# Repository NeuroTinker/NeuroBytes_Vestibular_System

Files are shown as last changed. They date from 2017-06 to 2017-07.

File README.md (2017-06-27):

# NeuroBytes Vestibular System
NeuroBytes are open-source hardware neuron simulators designed and sold by [NeuroTinker, LLC](http://www.neurotinker.com/). The Vestibular System boards emulate the portion of the inner ear responsible for orientation.  

All NeuroBytes products are based on the ST32L0x series of ARM Cortex-M0+ 32-bit microcontrollers. The boards were designed in KiCad and Inkscape and are released under the terms of the GPL, v3.0.

This repository is a continuation of the 8-bit ATtiny design called [NeuroBytes v0.91](https://github.com/zakqwy/neurobytes). The two series are not compatible.

## Project Status
This project is in alpha. The firmware is in progress and the API may change at any time. The PCB design is physically tested but has not yet been manufactured at scale.

## More Information
The NeuroBytes GitHub repositories store engineering information and make the design history of the project available to the public. Hardware- and firmware-specific README.md files can be found in their appropriate subdirectories. 

We encourage community involvement in our efforts, keeping in mind that hardware availability is currently quite limited. For product availability, operating guidelines, curricula, and information about NeuroTinker, LLC, head to neurotinker.com. Further technical logs are also at https://hackaday.io/project/3339-neurobytes.

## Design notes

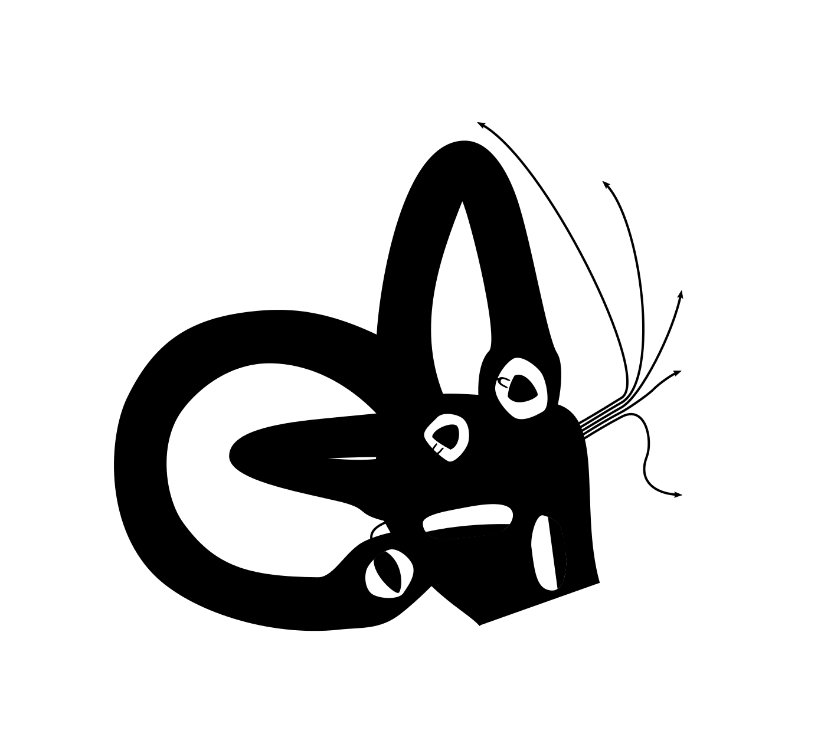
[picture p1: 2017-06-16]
HARDWARE/cu.png

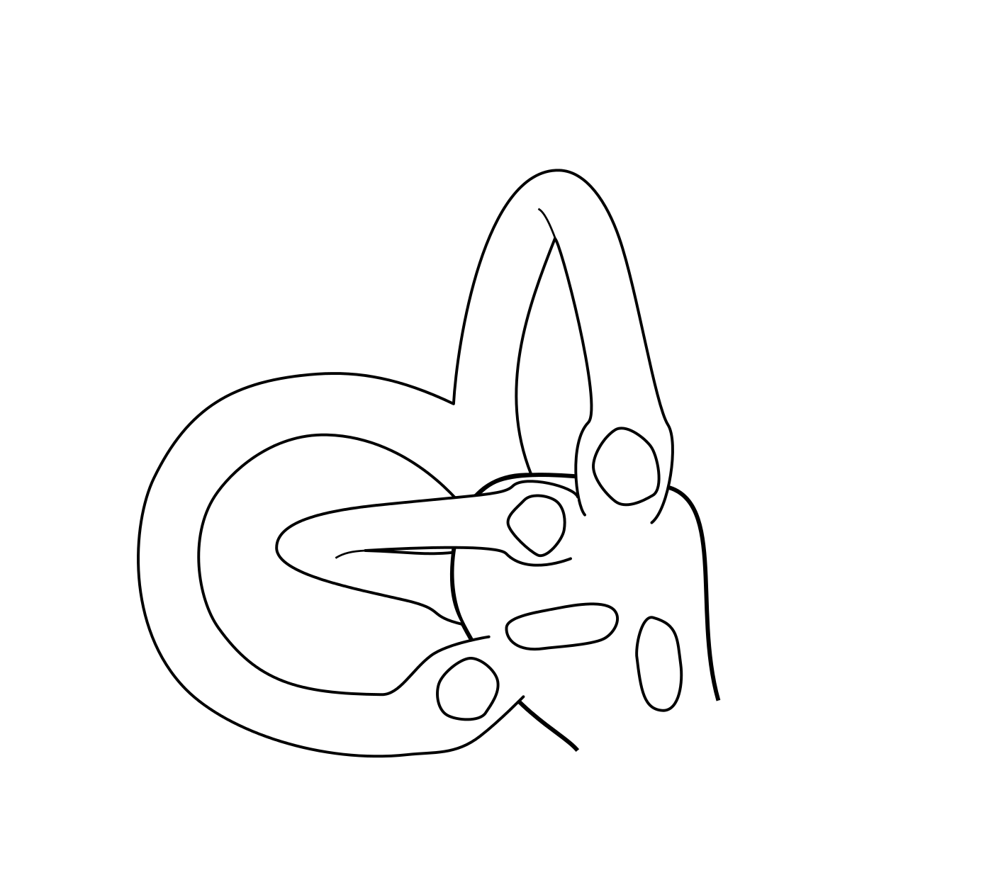
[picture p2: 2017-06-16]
HARDWARE/silk.png

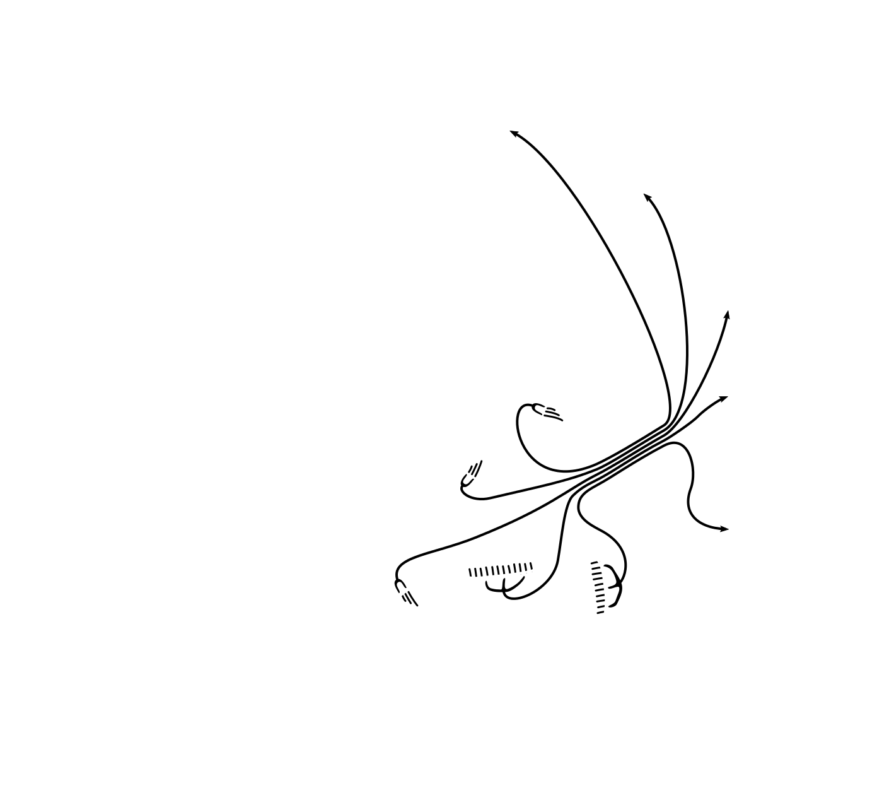
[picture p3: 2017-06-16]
HARDWARE/mask.png

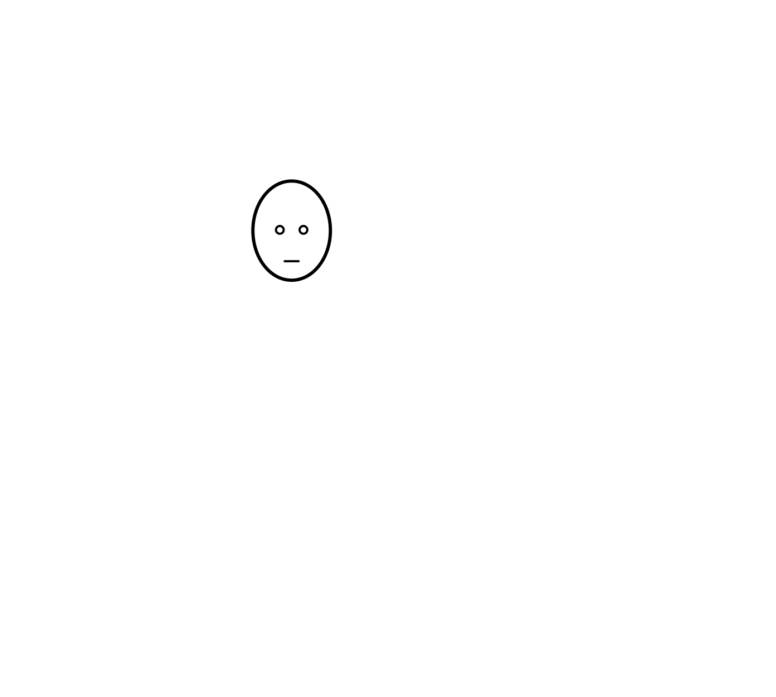
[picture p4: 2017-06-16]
HARDWARE/face.png

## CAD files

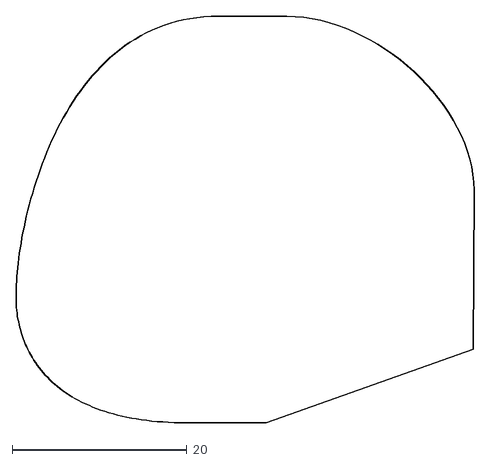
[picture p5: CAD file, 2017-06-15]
HARDWARE/NeuroBytes_Vestibular_System.dxf
52.3 x 46.4

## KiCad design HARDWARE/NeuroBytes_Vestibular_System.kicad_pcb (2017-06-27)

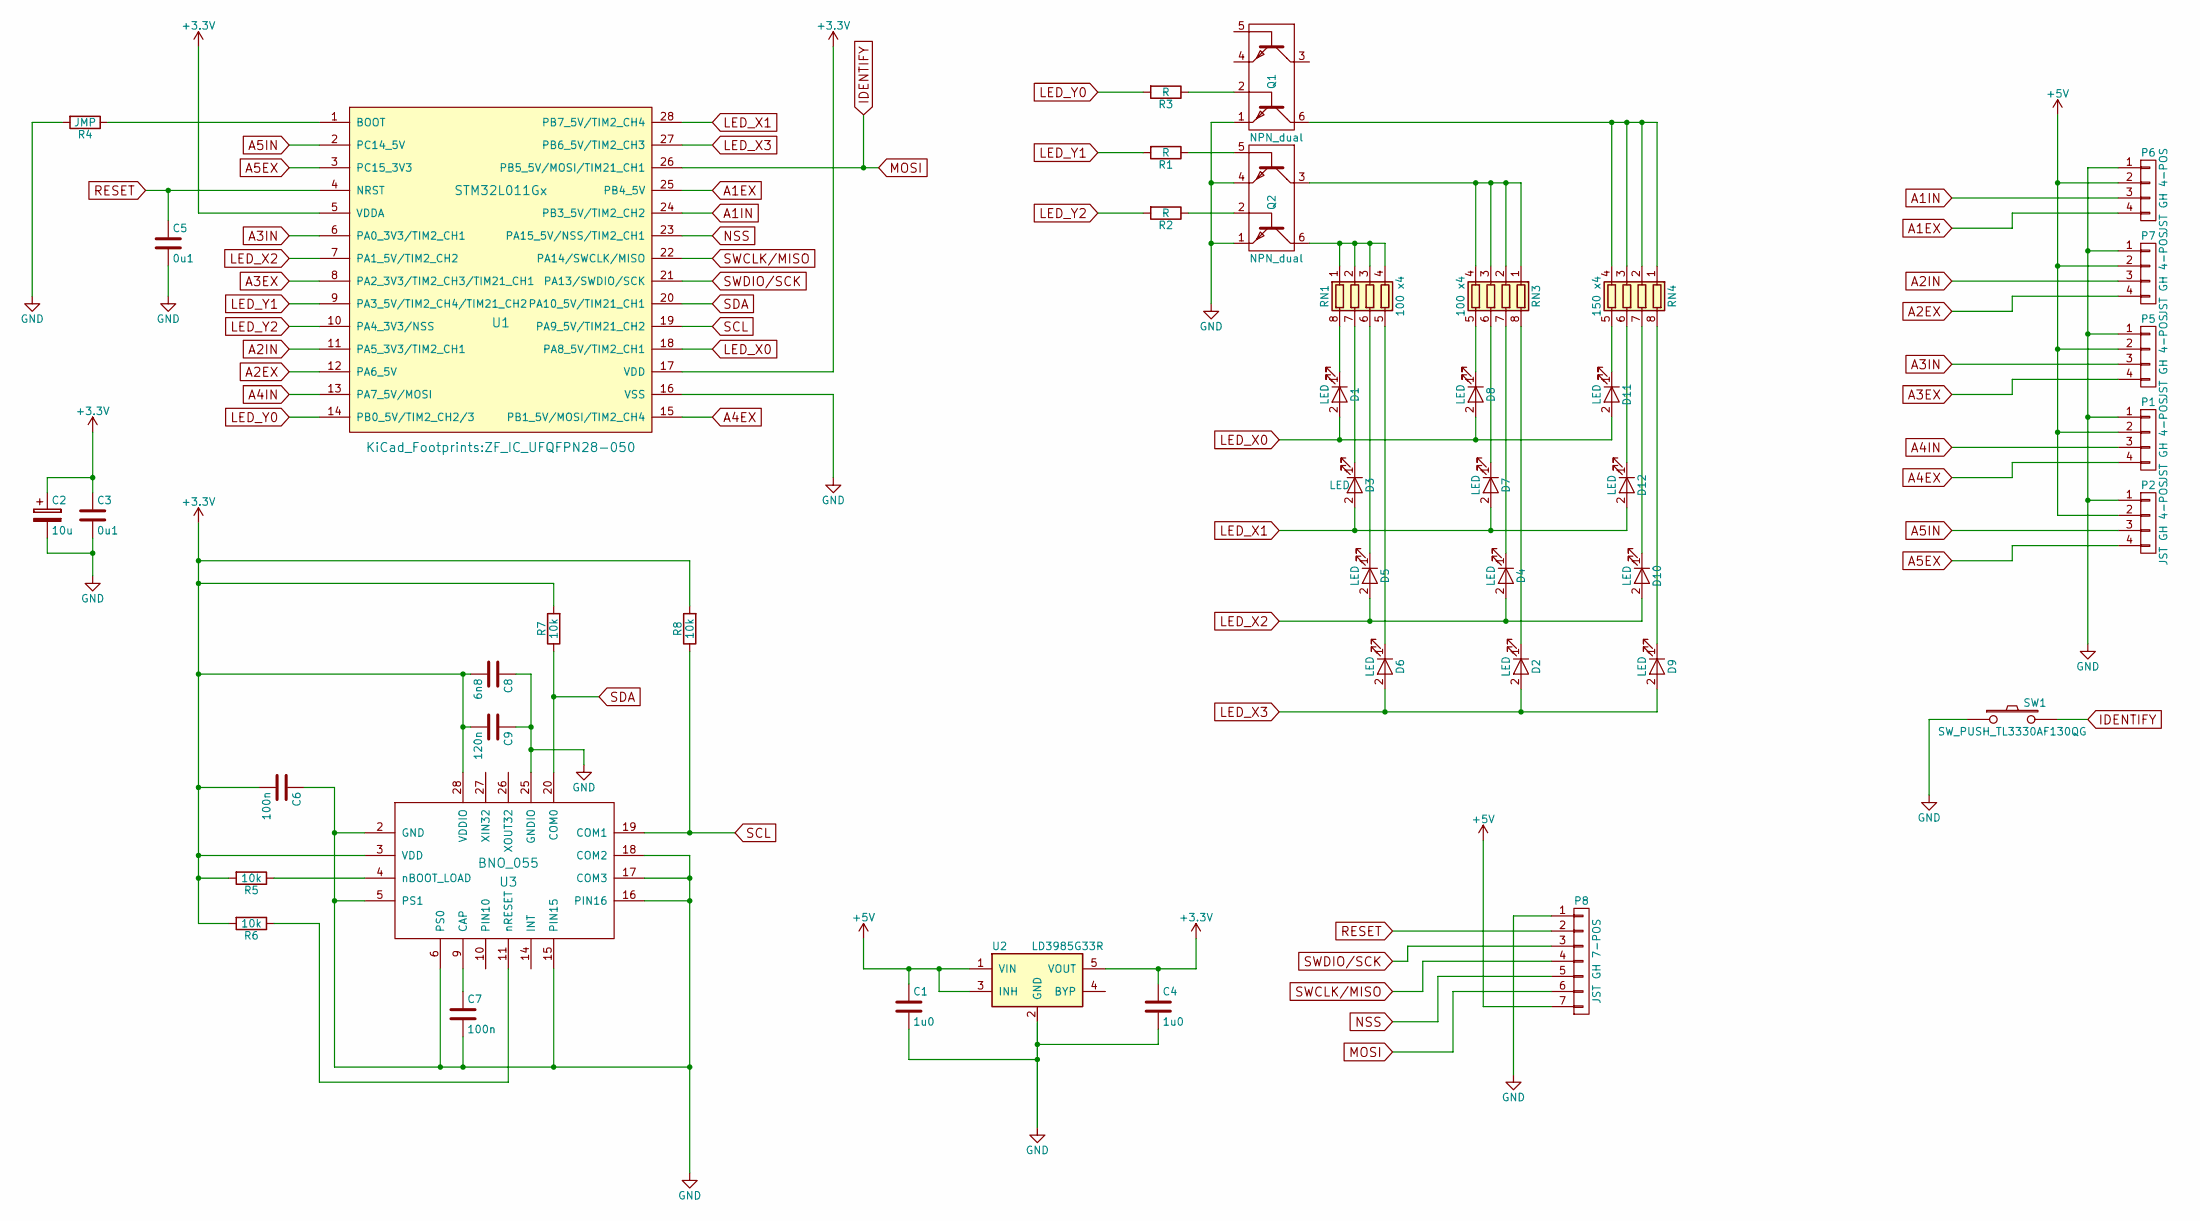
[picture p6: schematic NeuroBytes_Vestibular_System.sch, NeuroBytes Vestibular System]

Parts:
C1, C4: 1u0; ZF_SMD_NonPol_0603
C2: 10u; ZF_SMD_pol_1206
C3, C5: 0u1; ZF_SMD_NonPol_0402_cap
C6, C7: 100n; ZF_SMD_NonPol_0402_cap
C8: 6n8; ZF_SMD_NonPol_0402_cap
C9: 120n; ZF_SMD_NonPol_0402_cap
D1, D2, D3, D4, D5, D6, D7, D8, D9, D10, D11, D12: LED; ZF_SMD_NonPol_0402
P1, P2, P5, P6, P7: JST GH 4-POS; ZF_CONN_JST_GH
P8: JST GH 7-POS; ZF_CONN_JST_GH_7POS
Q1, Q2: NPN_dual; ZF_SMD_SOT-363
R1, R2, R3: R; ZF_SMD_NonPol_0402
R4: JMP; ZF_SMD_NonPol_0402
R5, R6, R7, R8: 10k; ZF_SMD_NonPol_0402
RN1, RN3: 100 x4; ZF_RN_4iso_CTS-0804
RN4: 150 x4; ZF_RN_4iso_CTS-0804
SW1: SW_PUSH_TL3330AF130QG; ZF_SW_Momentary_SideMtg
U1: STM32L011Gx; ZF_IC_UFQFPN28-050
U2: LD3985G33R; ZF_SOT23-5L
U3: BNO_055; ZF_IC_28LGA

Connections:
+3V3: C2.1, C3.1, C4.1, C6.2, C8.2, C9.2, R5.2, R6.2, R7.2, R8.2, U1.5 (VDDA), U1.17 (VDD), U2.5 (VOUT), U3.3 (VDD), U3.28 (VDDIO)
+5V: C1.1, P1.2, P2.2, P5.2, P6.2, P7.2, P8.7, U2.1 (VIN), U2.3 (INH)
A1EX: P6.4, U1.25 (PB4_5V)
A1IN: P6.3, U1.24 (PB3_5V/TIM2_CH2)
A2EX: P7.4, U1.12 (PA6_5V)
A2IN: P7.3, U1.11 (PA5_3V3/TIM2_CH1)
A3EX: P5.4, U1.8 (PA2_3V3/TIM2_CH3/TIM21_CH1)
A3IN: P5.3, U1.6 (PA0_3V3/TIM2_CH1)
A4EX: P1.4, U1.15 (PB1_5V/MOSI/TIM2_CH4)
A4IN: P1.3, U1.13 (PA7_5V/MOSI)
A5EX: P2.4, U1.3 (PC15_3V3)
A5IN: P2.3, U1.2 (PC14_5V)
GND: C1.2, C2.2, C3.2, C4.2, C5.2, C6.1, C7.2, C8.1, C9.1, P1.1, P2.1, P5.1, P6.1, P7.1, P8.1, Q1.1, Q2.1, Q2.4, R4.2, SW1.1, U1.16 (VSS), U2.2 (GND), U3.2 (GND), U3.5 (PS1), U3.6 (PS0), U3.15 (PIN15), U3.16 (PIN16), U3.17 (COM3), U3.18 (COM2), U3.25 (GNDIO)
IDENTIFY: P8.6, SW1.2, U1.26 (PB5_5V/MOSI/TIM21_CH1)
LED_X0: D1.2 (A), D8.2 (A), D11.2 (A), U1.18 (PA8_5V/TIM2_CH1)
LED_X1: D3.2 (A), D7.2 (A), D12.2 (A), U1.28 (PB7_5V/TIM2_CH4)
LED_X2: D4.2 (A), D5.2 (A), D10.2 (A), U1.7 (PA1_5V/TIM2_CH2)
LED_X3: D2.2 (A), D6.2 (A), D9.2 (A), U1.27 (PB6_5V/TIM2_CH3)
LED_Y0: R3.2, U1.14 (PB0_5V/TIM2_CH2/3)
LED_Y1: R1.2, U1.9 (PA3_5V/TIM2_CH4/TIM21_CH2)
LED_Y2: R2.2, U1.10 (PA4_3V3/NSS)
NSS: P8.5, U1.23 (PA15_5V/NSS/TIM2_CH1)
unnamed: C7.1, U3.9 (CAP)
unnamed: D1.1 (K), RN1.8 (R1.2)
unnamed: D2.1 (K), RN3.8 (R1.2)
unnamed: D3.1 (K), RN1.7 (R2.2)
unnamed: D4.1 (K), RN3.7 (R2.2)
unnamed: D5.1 (K), RN1.6 (R3.2)
unnamed: D6.1 (K), RN1.5 (R4.2)
unnamed: D7.1 (K), RN3.6 (R3.2)
unnamed: D8.1 (K), RN3.5 (R4.2)
unnamed: D9.1 (K), RN4.8 (R1.2)
unnamed: D10.1 (K), RN4.7 (R2.2)
unnamed: D11.1 (K), RN4.5 (R4.2)
unnamed: D12.1 (K), RN4.6 (R3.2)
unnamed: Q1.2 (BASE2), R3.1
unnamed: Q1.6, RN4.1 (R1.1), RN4.2 (R2.1), RN4.3 (R3.1), RN4.4 (R4.1)
unnamed: Q2.2 (BASE2), R2.1
unnamed: Q2.3, RN3.1 (R1.1), RN3.2 (R2.1), RN3.3 (R3.1), RN3.4 (R4.1)
unnamed: Q2.5 (BASE1), R1.1
unnamed: Q2.6, RN1.1 (R1.1), RN1.2 (R2.1), RN1.3 (R3.1), RN1.4 (R4.1)
unnamed: R4.1, U1.1 (BOOT)
unnamed: R5.1, U3.4 (nBOOT_LOAD)
unnamed: R6.1, U3.11 (nRESET)
RESET: C5.1, P8.2, U1.4 (NRST)
SCL: R8.1, U1.19 (PA9_5V/TIM21_CH2), U3.19 (COM1)
SDA: R7.1, U1.20 (PA10_5V/TIM21_CH1), U3.20 (COM0)
SWCLK/MISO: P8.4, U1.22 (PA14/SWCLK/MISO)
SWDIO/SCK: P8.3, U1.21 (PA13/SWDIO/SCK)

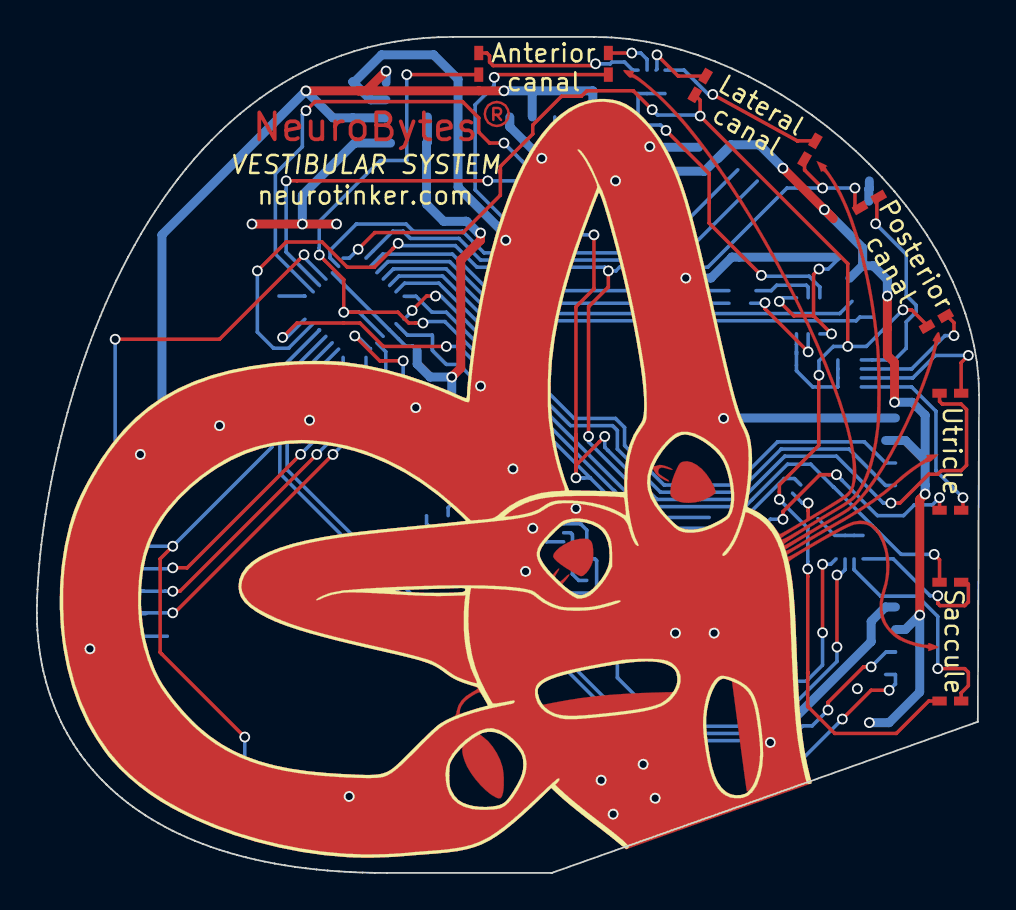
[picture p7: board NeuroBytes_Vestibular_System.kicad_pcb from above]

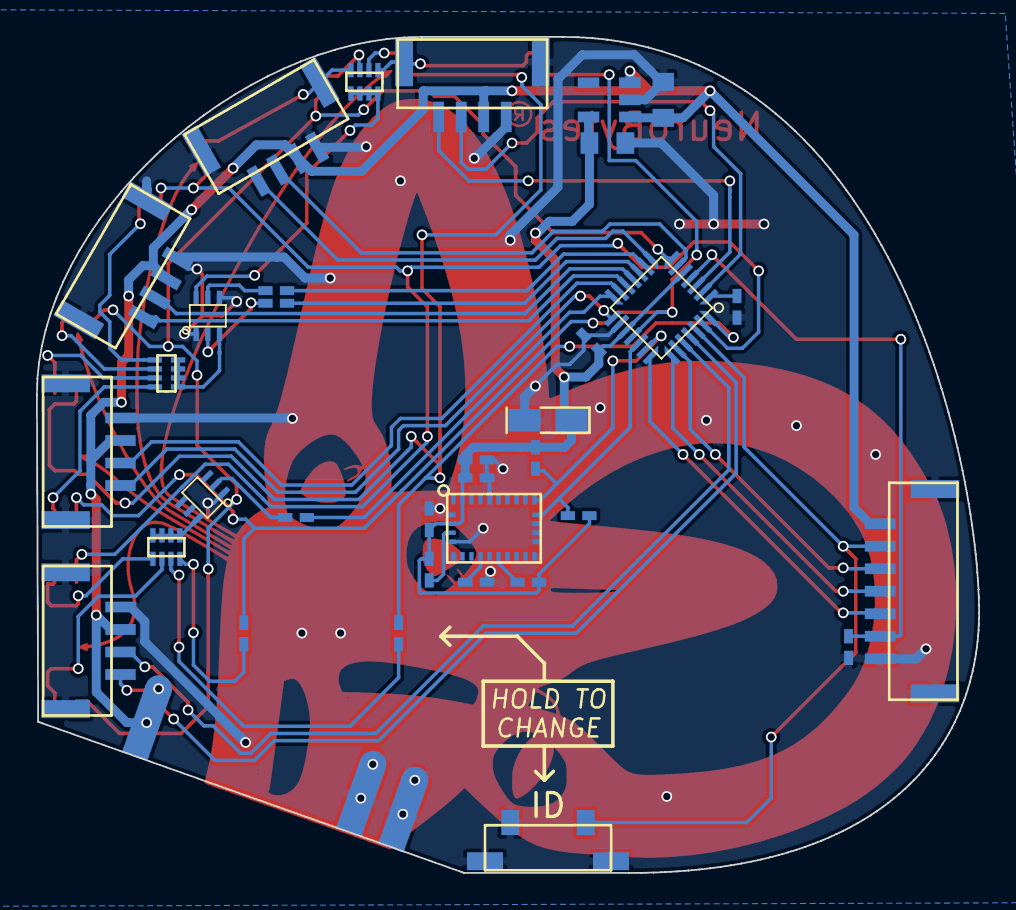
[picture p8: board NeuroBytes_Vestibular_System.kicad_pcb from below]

Board: 2 copper layers, 52.3 x 46.4 mm, 44 parts (34 on the bottom side), 49 nets.

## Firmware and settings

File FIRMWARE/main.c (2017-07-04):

#include <libopencm3/stm32/rcc.h>
#include <libopencm3/stm32/gpio.h>
#include <libopencm3/stm32/timer.h>
#include <libopencm3/cm3/nvic.h>
#include <libopencm3/cm3/systick.h>
#include <string.h>

#include "mini-printf.h"
#include "HAL.h"

int main(void)
{
	int i;
	int slow_count = 0;
	imu_data IMU = {0,0,0,0,0};


	clock_setup();
	gpio_setup();
	tim_setup();
	systick_setup(100); //systick in microseconds
	i2c_setup();
	usart_setup();
	char strDisp[20];

	for (i=0;i<20;i++)
	{
		strDisp[i] = 0;
	}

	for (i=0;i<5000000;i++)
	{
		__asm__("nop");
	}

	i2c_write(0x3D, 0x0); //OPR_MODE register, config mode
	i2c_write(0x3E, 0x0); //PWR_MODE register, normal
	i2c_write(0x07, 0x01); //Page ID, switch to page 1
	i2c_write(0x0A, 0x3C); //change gyro range to 125dps @32Hz
	//i2c_write(0x3B, 0x01); //change ACC_unit to mg
	i2c_write(0x07, 0x00); //Page ID, switch to page 0
	i2c_write(0x3D, 0x8); //OPR_MODE register, IMU mode	

	for (i=0;i<50000;i++)
	{
		__asm__("nop");
	}

	for(;;)
	{
		if (main_tick == 1) 
		{	//main tick every 100 us
			main_tick = 0;
		


			slow_count++;
			if (slow_count > 50)
			{
				slow_count = 0;
				getIMU(&IMU);
				mini_snprintf(strDisp, 20, "%d\n", IMU.accel_utr);
				usart_print(strDisp);
				scaleIMU(&IMU);
				setLEDs(&IMU, &LEDs);
			}
		}
	}
}

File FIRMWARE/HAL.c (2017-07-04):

#include <libopencm3/stm32/rcc.h>
#include <libopencm3/stm32/gpio.h>
#include <libopencm3/stm32/timer.h>
#include <libopencm3/cm3/nvic.h>
#include <libopencm3/cm3/systick.h>
#include <string.h>

#include "HAL.h"

volatile uint8_t tick = 0;
volatile uint8_t main_tick = 0;
volatile led_array LEDs = {0,0,0,0,0,0,0,0,0,0,0};

void sys_tick_handler(void)
{
	// Switch TIM21 ISR to this
}

void systick_setup(int xms) 
{
	systick_set_clocksource(STK_CSR_CLKSOURCE_EXT);
	STK_CVR = 0;
	systick_set_reload(2000 * xms);
	systick_counter_enable();
	systick_interrupt_enable();
}

void clock_setup(void)
{
	/*	Set clock source to 16 MHz High-Speed Internal oscillator and turn it on */
	rcc_set_sysclk_source(RCC_HSI16);
	rcc_osc_on(RCC_HSI16);
}

void gpio_setup(void)
{
	/*	Enable GPIO clocks */
	rcc_periph_clock_enable(RCC_GPIOA);
	rcc_periph_clock_enable(RCC_GPIOB);
	rcc_periph_clock_enable(RCC_GPIOC);

	/*	Set up LED matrix
		X pins on TIM2 PWM outputs
		Y pins on .. other GPIOs */
	gpio_mode_setup(PORT_X0_LED, GPIO_MODE_AF, GPIO_PUPD_NONE, PIN_X0_LED);
	gpio_mode_setup(PORT_X1_LED, GPIO_MODE_AF, GPIO_PUPD_NONE, PIN_X1_LED);
	gpio_mode_setup(PORT_X2_LED, GPIO_MODE_AF, GPIO_PUPD_NONE, PIN_X2_LED);
	gpio_mode_setup(PORT_X3_LED, GPIO_MODE_AF, GPIO_PUPD_NONE, PIN_X3_LED);
	gpio_mode_setup(PORT_Y0_LED, GPIO_MODE_OUTPUT, GPIO_PUPD_NONE, PIN_Y0_LED);
	gpio_mode_setup(PORT_Y1_LED, GPIO_MODE_OUTPUT, GPIO_PUPD_NONE, PIN_Y1_LED);
	gpio_mode_setup(PORT_Y2_LED, GPIO_MODE_OUTPUT, GPIO_PUPD_NONE, PIN_Y2_LED);
	gpio_set_output_options(PORT_X0_LED, GPIO_OTYPE_PP, GPIO_OSPEED_HIGH, PIN_X0_LED);	
	gpio_set_output_options(PORT_X1_LED, GPIO_OTYPE_PP, GPIO_OSPEED_HIGH, PIN_X1_LED);	
	gpio_set_output_options(PORT_X2_LED, GPIO_OTYPE_PP, GPIO_OSPEED_HIGH, PIN_X2_LED);	
	gpio_set_output_options(PORT_X3_LED, GPIO_OTYPE_PP, GPIO_OSPEED_HIGH, PIN_X3_LED);	
	gpio_set_af(PORT_X0_LED, GPIO_AF5, PIN_X0_LED);
	gpio_set_af(PORT_X1_LED, GPIO_AF5, PIN_X1_LED);
	gpio_set_af(PORT_X2_LED, GPIO_AF2, PIN_X2_LED);
	gpio_set_af(PORT_X3_LED, GPIO_AF5, PIN_X3_LED);


	/*	Set up button input */
	gpio_mode_setup(PORT_IDENTIFY, GPIO_MODE_INPUT, GPIO_PUPD_PULLDOWN, PIN_IDENTIFY);
}

void tim_setup(void)
{
	/* 	Enable and reset TIM2 clock */
	rcc_periph_clock_enable(RCC_TIM2);
	timer_reset(TIM2);

	/* 	Set up TIM2 mode to no clock divider ratio, edge alignment, and up direction */
	timer_set_mode(TIM2, TIM_CR1_CKD_CK_INT, TIM_CR1_CMS_EDGE, TIM_CR1_DIR_UP);

	/*	Set prescaler to 0: 16 MHz clock */
	timer_set_prescaler(TIM2, 0);
	timer_set_period(TIM2, 1023);

	/* 	Set TIM2 Output Compare mode to PWM1 on channels 1,2,3, and 4 */ 
	timer_set_oc_mode(TIM2, TIM_OC1, TIM_OCM_PWM1);
	timer_set_oc_mode(TIM2, TIM_OC2, TIM_OCM_PWM1);
	timer_set_oc_mode(TIM2, TIM_OC3, TIM_OCM_PWM1);
	timer_set_oc_mode(TIM2, TIM_OC4, TIM_OCM_PWM1);

	/* 	Set starting output compare values */
	timer_set_oc_value(TIM2, TIM_OC1, 0);
	timer_set_oc_value(TIM2, TIM_OC2, 0);
	timer_set_oc_value(TIM2, TIM_OC3, 0);
	timer_set_oc_value(TIM2, TIM_OC4, 0);

	/* 	Enable outputs */ 
	timer_enable_oc_output(TIM2, TIM_OC1);
	timer_enable_oc_output(TIM2, TIM_OC2);
	timer_enable_oc_output(TIM2, TIM_OC3);
	timer_enable_oc_output(TIM2, TIM_OC4);
	
	/*	Enable counter */
	timer_enable_counter(TIM2);

    // Enable TIM2 interrupts (600 us)
    timer_enable_irq(TIM2, TIM_DIER_UIE);

    // setup TIM21

    MMIO32((RCC_BASE) + 0x34) |= (1<<2); //Enable TIM21
    MMIO32((RCC_BASE) + 0x24) |= (1<<2); //Set reset bit, TIM21
    MMIO32((RCC_BASE) + 0x24) &= ~(1<<2); //Clear reset bit, TIM21

    /*    TIM21 control register 1 (TIMx_CR1): */
    MMIO32((TIM21_BASE) + 0x00) &= ~((1<<5) | (1<<6)); //Edge-aligned (default setting)
    MMIO32((TIM21_BASE) + 0x00) &= ~((1<<9) | (1<<10)); //No clock division (default setting)
    MMIO32((TIM21_BASE) + 0x00) &= ~(1<<4); //Up direction (default setting)
           
    /*    TIM21 interrupt enable register (TIMx_DIER): */
    MMIO32((TIM21_BASE) + 0x0C) |= (1<<0); //Enable update interrupts

    /*    TIM21 prescaler (TIMx_PSC): */
    MMIO32((TIM21_BASE) + 0x28) = 7; //prescaler = clk/8 (see datasheet, they add one for convenience)

    /*    TIM21 auto-reload register (TIMx_ARR): */
    MMIO32((TIM21_BASE) + 0x2C) = 200; //100 us interrupts (with clk/8 prescaler)
   
    /*    Enable TIM21 counter: */
    MMIO32((TIM21_BASE) + 0x00) |= (1<<0);

    nvic_enable_irq(NVIC_TIM21_IRQ);
    nvic_set_priority(NVIC_TIM21_IRQ, 1);
}

void usart_setup(void)
{
	gpio_mode_setup(PORT_USART, GPIO_MODE_AF, GPIO_PUPD_NONE, PIN_USART_TX);
	gpio_set_af(PORT_USART, GPIO_AF4, PIN_USART_TX);

	rcc_periph_clock_enable(RCC_USART2);
	
	// USART_BRR: set baud rate
	MMIO32((USART2_BASE) + 0x0C) = 139; // 16 MHz / 115200 baud
	
	// default 8-bit character length
	// default 1 stop bit
	// default no parity
	// default no flow control

	// USART_CR1: enable USART2
	MMIO32((USART2_BASE) + 0x00) |= (1<<0);
}

void usart_send(uint8_t word)
{
	while ((MMIO32((USART2_BASE) + 0x1C) & (1<<7)) == 0); // ensure transmit register is empty

		MMIO32((USART2_BASE) + 0x00) |= (1<<3); // enable transmit
		MMIO32((USART2_BASE) + 0x28) = (word & 0xFF); // write data to USART_TDR
}

void usart_print(char *msg)
{
	int len = strlen(msg);
	int i;
	for (i=0;i<len;i++)
	{
		usart_send((uint8_t)*msg++);
	}
}



void i2c_setup(void)
{
/*	BNO055 on PA10 (SDA) and PA9 (SCL)
	I2C1 via AF1 */
	rcc_periph_clock_enable(RCC_I2C1);
	gpio_mode_setup(PORT_I2C_SDA, GPIO_MODE_AF, GPIO_PUPD_NONE, PIN_I2C_SDA); 
	gpio_mode_setup(PORT_I2C_SCL, GPIO_MODE_AF, GPIO_PUPD_NONE, PIN_I2C_SCL); 
	gpio_set_af(PORT_I2C_SDA, GPIO_AF1, PIN_I2C_SDA);
	gpio_set_af(PORT_I2C_SCL, GPIO_AF1, PIN_I2C_SCL);
	rcc_periph_reset_pulse(RST_I2C1);

/*	Manual I2C register setup. Note that the system defaults to 7-bit addressing,
	clock stretching, and analog noise filtering (so these don't need to be configured). 
	Timer settings are taken from the STM32L0 reference manual Table 98 for 100 kHz
	standard mode with F(i2cclk) = 16 MHz. See also I2C initialization flowchart (figure 178). */

/*	Make sure the I2C peripheral is disabled by clearing PE */
	MMIO32(I2C1_BASE + 0x00) &= ~(1<<0);
	
/*	I2C control register 1: I2C_CR1 */
	MMIO32(I2C1_BASE + 0x00) |= (0x3<<8); //set DNF (digital filter) to 3 clock cycles 

/*	I2C timer register: I2C_TIMINGR */
	MMIO32(I2C1_BASE + 0x10) |= (3<<28); //set PRESC to 3
	MMIO32(I2C1_BASE + 0x10) |= (0x4 << 20); //set SCLDEL to 0x4
	MMIO32(I2C1_BASE + 0x10) |= (0x2 << 16); //set SDADEL to 0x2
	MMIO32(I2C1_BASE + 0x10) |= (0xF << 8); //set SCLH to 0xF
	MMIO32(I2C1_BASE + 0x10) |= (0x13 << 0); //set SCLL to 0x13

/*	Enable the I2C peripheral by setting PE */		
	MMIO32(I2C1_BASE + 0x00) |= (1<<0);
}
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

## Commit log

2017-05-28 Initial commit. Made BNO055 schematic symbol and footprint. First draft of schematic. Grouped components on PCB. No artwork or routing yet.
    [NeuroBytes_Vestibular_System.kicad_pcb, NeuroBytes_Vestibular_System.sch]
2017-06-15 Updated graphics to improve 3D orthoganol canal effect.
    [NeuroBytes_Vestibular_System.dxf, NeuroBytes_Vestibular_System.kicad_pcb, NeuroBytes_Vestibular_System.sch]
2017-06-16 first PCB routing revision.
    [NeuroBytes_Vestibular_System.kicad_pcb, NeuroBytes_Vestibular_System.sch]
2017-06-27 minor PCB updates. generated paste gerber for stencil.
    [NeuroBytes_Vestibular_System.kicad_pcb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]
2017-06-27 reversed LEDs
    [NeuroBytes_Vestibular_System.kicad_pcb, NeuroBytes_Vestibular_System.sch]
2017-06-28 First firmware test with BNO055 and multiplexed LEDs. No left/right switching, acceleration (utricle/saccule), comms, or NB output functions.
2017-06-28 swapped lateral and posterior canals. started testing accelerometer. pushed led matrix stuff to ISR. increased pwm frequency. regenerated gamma table.
    [HAL.c, HAL.h, main.c]

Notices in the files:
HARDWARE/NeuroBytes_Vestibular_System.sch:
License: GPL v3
